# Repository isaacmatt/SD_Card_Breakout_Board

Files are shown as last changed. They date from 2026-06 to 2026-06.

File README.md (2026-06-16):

# microSD Card Breakout (SPI, 3.3 V)

A minimal microSD card breakout board for 3.3 V microcontrollers, exposing the card over a 1-bit SPI interface on a 0.1" header. Designed as a hands-on KiCad project with a clean, manufacturable layout.

> **Status:** Schematic and PCB layout complete. ERC and DRC clean (0 violations, 0 unconnected). **Not yet fabricated or tested** — this is a design-stage project. Footprint assignment, layout, and manufacturing files are done; the board has not been ordered, assembled, or brought up.

---

## Overview

This is a passive breakout: it routes a microSD connector to a pin header with the minimum support circuitry required for reliable operation, and nothing else. No onboard microcontroller, voltage regulator, level shifter, or USB. You supply 3.3 V from a host, jumper the SPI lines across, and talk to the card using a standard SD library on the host side.

The design deliberately targets the common denominator across 3.3 V hosts:  **SPI 1-bit mode** . SDIO/4-bit is intentionally out of scope.

## Features

* microSD (TF) push-push connector with spring eject
* SPI 1-bit interface broken out to a 1×8 0.1" header
* Pull-ups on all data lines per the SD specification
* Local decoupling (100 nF + 1 µF) at the connector's VDD pin
* 2-layer board with ground pours on both layers, via-stitched
* All passives 0603 (hand-solder friendly); designed for low-cost fab + assembly

## Specifications

| Property | Value |
| --- | --- |
| Interface | SPI, 1-bit |
| Logic / supply voltage | 3.3 V only (**not 5 V tolerant** ) |
| Layers | 2 (signals on top, GND pours both layers) |
| Connector | SHOU HAN TF PUSH, push-push, 8 contacts + grounded shell |
| Connector LCSC P/N | C393941 |
| Card detection | Firmware (no hardware detect switch — see below) |
| EDA tool | KiCad 10 |

## Supported hosts

| Host | Supported | Notes |
| --- | --- | --- |
| Raspberry Pi Pico W (RP2040) | ✅ Direct | 3.3 V SPI host |
| nRF52840 | ✅ Direct | 3.3 V SPI host |
| Arduino Uno (ATmega328P) | ⚠️ Not directly | 5 V logic — its SPI outputs would overdrive a 3.3 V card. Requires an external level shifter on SCK/MOSI/CS. Not included on this board. |

microSD cards operate at 2.7–3.6 V and are not 5 V tolerant. Any 5 V-logic host requires level shifting on the host-driven lines (SCK, MOSI, CS). MISO returns 3.3 V, which a 5 V AVR reads as a valid logic high, so only the outbound lines need shifting.

## Pinout

### microSD contact → SPI mapping

The microSD pinout is standardized. In SPI mode:

| Contact | Card name | SPI role | On-board support |
| --- | --- | --- | --- |
| 1 | DAT2 | unused | 10 kΩ pull-up |
| 2 | CD/DAT3 | **CS** | 10 kΩ pull-up |
| 3 | CMD | **MOSI** | 10 kΩ pull-up |
| 4 | VDD | power | 100 nF + 1 µF decoupling |
| 5 | CLK | **SCK**  | — |
| 6 | VSS | ground | — |
| 7 | DAT0 | **MISO** | 10 kΩ pull-up |
| 8 | DAT1 | unused | 10 kΩ pull-up |
| shell | shield | — | tied to GND |

DAT1 and DAT2 are unused in SPI mode but are pulled high so the card does not float into an undefined state at power-up.

### J2 header (1×8, 2.54 mm)

| Pin | Signal |
| --- | --- |
| 1 | 3V3 |
| 2 | GND |
| 3 | CS |
| 4 | SCK |
| 5 | MOSI |
| 6 | MISO |
| 7 | GND |
| 8 | GND |

The header order was chosen to keep board routing clean; the two extra grounds improve the jumper-wire return path.

## Card detection

The chosen connector has **no mechanical card-detect switch** — only the 8 SD contacts and a grounded shell. Card presence is therefore detected in  **firmware** : attempt to initialize the card over SPI, and if it responds, a card is present. This is standard practice for SD breakouts and removes a dependency on an underdocumented mechanical feature.

## Bill of Materials

| Ref | Value | Package | Notes |
| --- | --- | --- | --- |
| J1  | microSD connector | SMD | SHOU HAN TF PUSH, LCSC C393941 |
| J2  | 1×8 header | 2.54 mm THT | Hand-soldered after SMT assembly |
| C1  | 100 nF | 0603 | Decoupling at VDD |
| C2  | 1 µF | 0603 | Bulk decoupling at VDD |
| R1  | 10 kΩ | 0603 | CS pull-up |
| R2  | 10 kΩ | 0603 | MOSI pull-up |
| R3  | 10 kΩ | 0603 | MISO pull-up |
| R4  | 10 kΩ | 0603 | DAT1 pull-up |
| R5  | 10 kΩ | 0603 | DAT2 pull-up |

## Design decisions & rationale

* **3.3 V-only, passive breakout.** Keeps the board simple and lets it work with any 3.3 V SPI host. Level shifting is treated as a host-side concern, not baked in.
* **SPI 1-bit mode.** The common denominator across target hosts; also simplifies the breakout to CS/SCK/MOSI/MISO + power.
* **Pull-ups on all data lines.** Per the SD physical-layer specification, including the unused DAT1/DAT2 so they don't float; CS is pulled high so it idles correctly.
* **Decoupling placed at the connector's VDD pin.** SD cards have real current inrush; the 100 nF + 1 µF sit immediately at the power pin where they're effective.
* **Connector selected for availability.** An active, in-stock, JLCPCB-assemblable part was prioritized over a "nicer" datasheet on an out-of-stock alternative — a manufacturability-driven choice.
* **Firmware card detection.** Chosen over relying on a hardware switch the connector doesn't have.
* **Dual-layer GND pour, via-stitched.** Grounds the connector shield, provides a low-impedance return, and ties both planes together.

## Manufacturing notes

Intended fab/assembly flow (JLCPCB):

1. Order bare PCBs + **economic SMT assembly** for the connector and 0603 passives.
2. Leave the **through-hole header (J2) off** the assembly and hand-solder it afterward — it's the easiest part and avoids THT assembly fees.
3. At the assembly stage, verify the connector's **pad-1 orientation** in the placement preview — connector rotation is the most common first-time assembly mistake.

The pull-up resistors and caps are all 0603 and the only THT part is the header, so the board is straightforward to assemble either by machine or by hand.

## Not included / limitations

* No level shifting — 3.3 V hosts only.
* No ESD protection — see roadmap.
* No mounting holes are electrically connected (the connector's holes are mechanical/NPTH).
* Untested; no firmware/driver provided. Use a standard SPI SD library on the host (e.g. Arduino `SD`/`SdFat`, CircuitPython `adafruit_sdcard`, or the RP2040/nRF SDKs).

## Roadmap (v2 ideas)

* Add a low-capacitance ESD/TVS array at the connector contacts (e.g. `USBLC6-2SC6` or a multi-channel low-cap array), placed before the pull-ups. Low capacitance matters so SPI edges aren't distorted.
* Optional level-shifted variant (e.g. `74LVC125` buffer + 3.3 V LDO) to support 5 V hosts like the Arduino Uno directly.
* Silkscreen the full header pinout next to J2 for at-a-glance jumpering.

## Repository structure

```
.
├── microSD_breakout.kicad_pro     # KiCad project
├── microSD_breakout.kicad_sch     # Schematic
├── microSD_breakout.kicad_pcb     # PCB layout
├── easyeda2kicad.pretty/          # Imported connector footprint
├── easyeda2kicad.kicad_sym        # Imported connector symbol
├── fab/                           # Gerbers, BOM, CPL (when generated)
├── docs/                          # Schematic / PCB / 3D renders
└── README.md
```

## Opening this project

The connector's symbol and footprint are **bundled in this repository** (`easyeda2kicad.pretty/`, `easyeda2kicad.kicad_sym`) so the project opens without external dependencies. The library tables reference them with the project-relative path variable `${KIPRJMOD}`, so the paths resolve correctly on any machine after cloning.

If KiCad reports a missing footprint or symbol after cloning, check that the footprint and symbol library tables point to the in-repo copies (Preferences → Manage Footprint/Symbol Libraries) using `${KIPRJMOD}/easyeda2kicad.pretty` and `${KIPRJMOD}/easyeda2kicad.kicad_sym`.

### Regenerating the connector footprint

The J1 footprint was imported from LCSC using [easyeda2kicad](https://github.com/uPesy/easyeda2kicad.py). To regenerate it from scratch:

```bash
pip install easyeda2kicad
easyeda2kicad --full --lcsc_id C393941
```

Then add the generated `easyeda2kicad.pretty` and `easyeda2kicad.kicad_sym` to your KiCad library tables. Using the EasyEDA/LCSC library this way ensures the footprint geometry matches JLCPCB's pick-and-place data for assembly.

## Wiring example

Connect the J2 header to your host's SPI pins. The exact host GPIO numbers depend on your board — fill in your host's SPI bus:

| J2 pin | Signal | → Host |
| --- | --- | --- |
| 1 | 3V3 | 3.3 V |
| 2 | GND | GND |
| 3 | CS | any GPIO used as chip-select |
| 4 | SCK | SPI clock |
| 5 | MOSI | SPI MOSI / TX |
| 6 | MISO | SPI MISO / RX |
| 7 | GND | GND |
| 8 | GND | GND |

## License

MIT — choose and add a `LICENSE` file. MIT is a common default for open hardware projects; adapt as you prefer.

## Author

**isaac-m** ([@isaacmatt](https://github.com/isaacmatt))

---

*Built in KiCad as a from-scratch PCB design exercise: connector selection and lifecycle/stock checking, third-party footprint import and verification, schematic capture, layout, ground-plane routing, and manufacturing-file preparation.*

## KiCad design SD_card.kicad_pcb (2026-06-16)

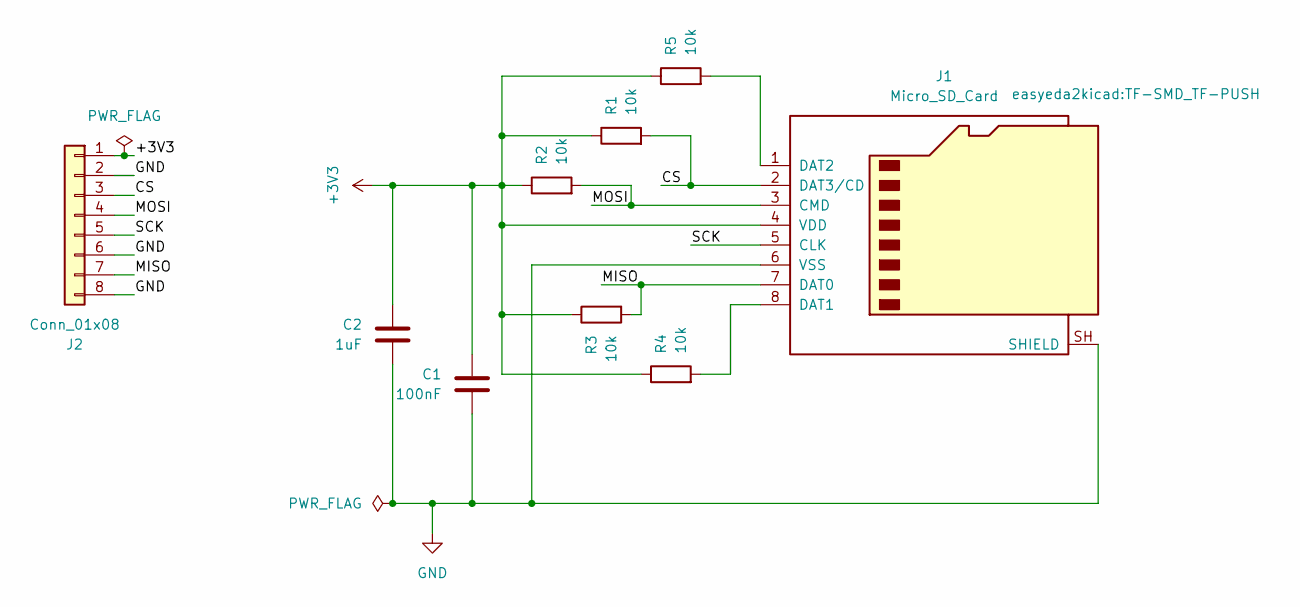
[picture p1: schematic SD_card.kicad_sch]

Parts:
C1: 100nF; C_0603_1608Metric
C2: 1uF; C_0603_1608Metric
J1: Micro_SD_Card; TF-SMD_TF-PUSH
J2: Conn_01x08; PinHeader_1x08_P2.54mm_Vertical
R1, R2, R3, R4, R5: 10k; R_0603_1608Metric

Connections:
+3V3: C1.1, C2.1, J1.4 (VDD), J2.1, R1.1, R2.1, R3.1, R4.1, R5.1
/CS: J1.2 (DAT3/CD), J2.3, R1.2
/MISO: J1.7 (DAT0), J2.7, R3.2
/MOSI: J1.3 (CMD), J2.4, R2.2
/SCK: J1.5 (CLK), J2.5
GND: C1.2, C2.2, J1.6 (VSS), J1.SH (SHIELD), J2.2, J2.6, J2.8
unnamed: J1.8 (DAT1), R4.2
unnamed: J1.1 (DAT2), R5.2

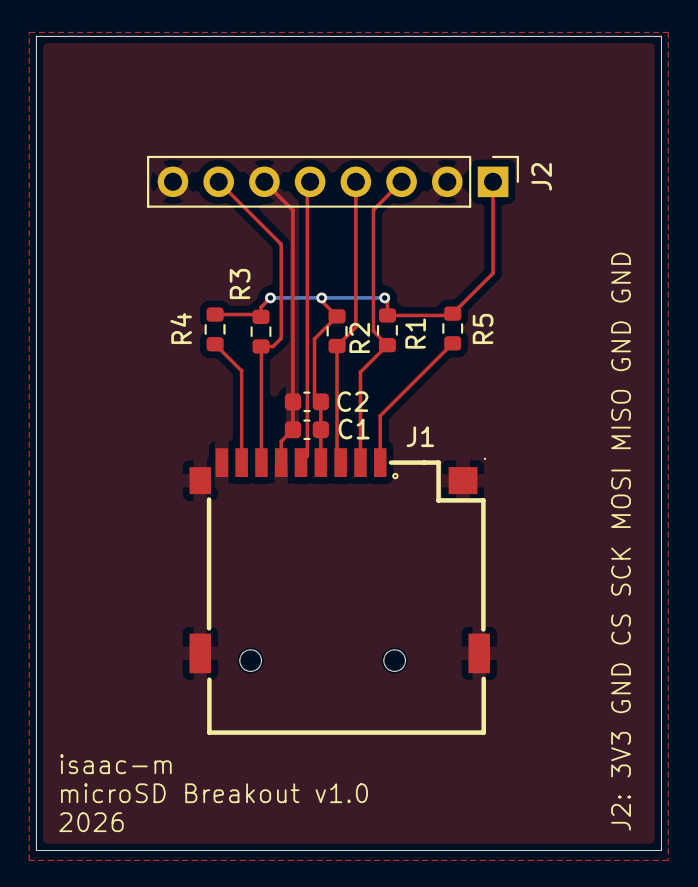
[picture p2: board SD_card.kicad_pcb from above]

Board: 2 copper layers, 34.7 x 45.2 mm, 9 parts (0 on the bottom side), 8 nets.

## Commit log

2026-06-12 Initial KiCad project setup
    Add schematic and PCB project files, README, CERN-OHL-P-2.0 license, and KiCad gitignore rules.
    [SD_card.kicad_pcb, SD_card.kicad_sch]
2026-06-16 Complete PCB layout, DRC clean
    Routed all signals on F.Cu, GND pours on both layers with
    stitching vias. Fixed imported connector footprint (courtyard,
    NPTH holes, shell-tab naming). Added silkscreen labeling.
    Ready for fab output generation.
    [SD_card.kicad_pcb]
2026-06-16 Add detailed README for microSD breakout
    Replace the minimal README with a comprehensive project document covering status, overview, features, specifications, supported hosts, pinout, BOM, design rationale, manufacturing notes, limitations, roadmap, repo layout, footprint regeneration steps, wiring examples, license and author. Updates project status to indicate schematic and PCB layout are complete and ERC/DRC-clean but the board is unfabricated and untested. Also documents that the connector footprint/symbol are bundled in-repo and provides assembly/ordering guidance.
